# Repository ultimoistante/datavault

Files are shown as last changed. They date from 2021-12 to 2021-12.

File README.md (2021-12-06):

# DataVault - a simple, cheap, and effective backup unit for cloud storage services

## preface
The reason I've built this device is rather simple: I have a private NextCloud instance running on a my small server where I (and my family) store some important data. Since it is not wise to keep "all eggs in one bucket", and since that "two copies are better than one", I made this device to automatically keep a synchronized copy of all my data (from my NextCloud server and from some GDrive accounts) to its SSD drive.

## the device
The device is rather simple: just an old Raspberry Pi model B+, a SATA SSD drive, an USB/SATA adapter, and an ESP8266 MCU board (NodeMCU).
Everything fits perfectly in the case of an old ADSL modem (Alice Gate Plus, by Pirelli/Telecom Italia).

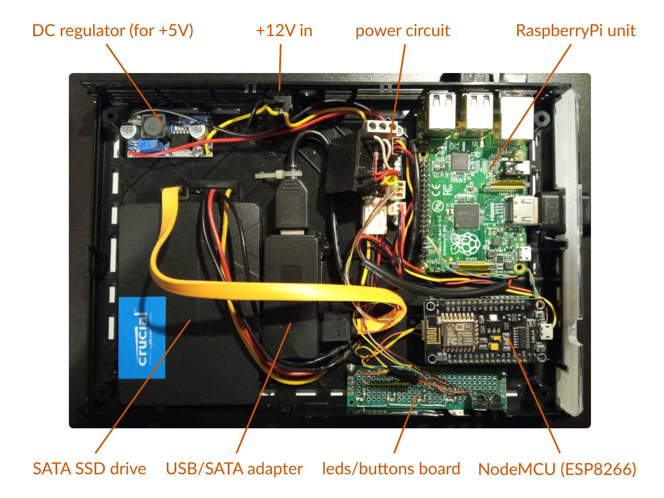
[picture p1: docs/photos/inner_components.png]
inner components

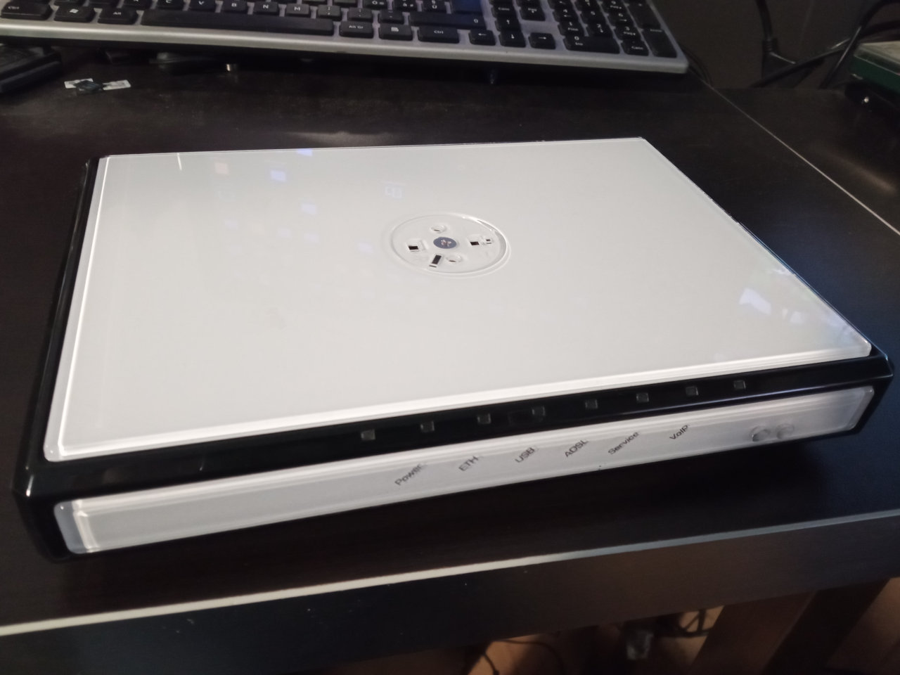
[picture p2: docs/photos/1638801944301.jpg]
outer 1

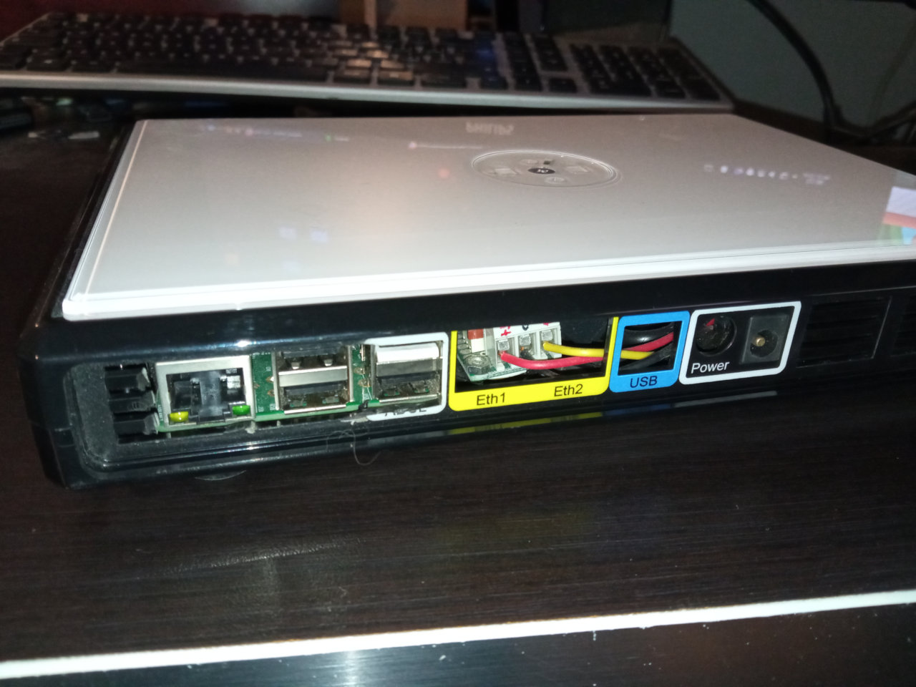
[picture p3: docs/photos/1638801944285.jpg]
outer 2

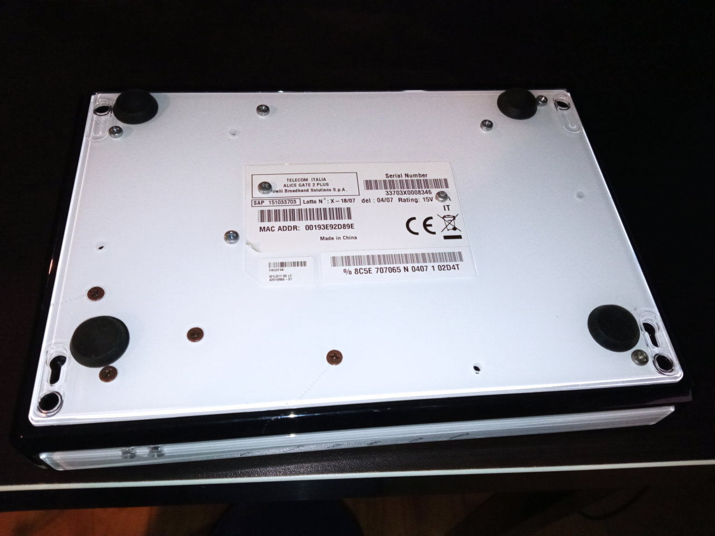
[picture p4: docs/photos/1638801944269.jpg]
outer 3


## working principle
Everything is powered by an external 12V DC adapter. In the box there is a DC stepdown regulator for +5V line. These two voltage levels are connected on the "power circuit" board.

The ESP8266 unit is always powered (consuming almost nothing), it's connected to home network via wifi, and it acts as a "timer" for the Raspberry Pi unit. Once a day (in my case during the night), it switches a relay giving power to the Raspberry Pi, that is connected to the network via ethernet cable. Once the RaspberryPi system it's booted, it starts a simple python application that sequentially runs some tasks defined in a json configuration file. Each task spawns an **RClone** (https://rclone.org/) subprocess that connects to the remote cloud repository and *syncs* (in one way mode) all remote files to local SATA SSD drive.

## the ESP8266 unit
Firmware and webservice sources are under **sources/esp8266** folder. The code was written using **PlatformIO** (https://platformio.org/) on VSCode.
Unlike *almost* every ESP8266 firmwares you can find on the network, to connect this device to the WiFi network you don't need to write your network credentials in the sources, since I've added an handy **WPS** feature. You just need to enable WPS on your router, and push the WPS button on the ESP8266 unit (connected to pin D6). Once successfully paired, the device will connect to NTP server, taking current date/time. I've also added a **mDNS** feature, so you can reach its settings page opening the address **http://dvctrl.local/** with a modern browser from your local network.

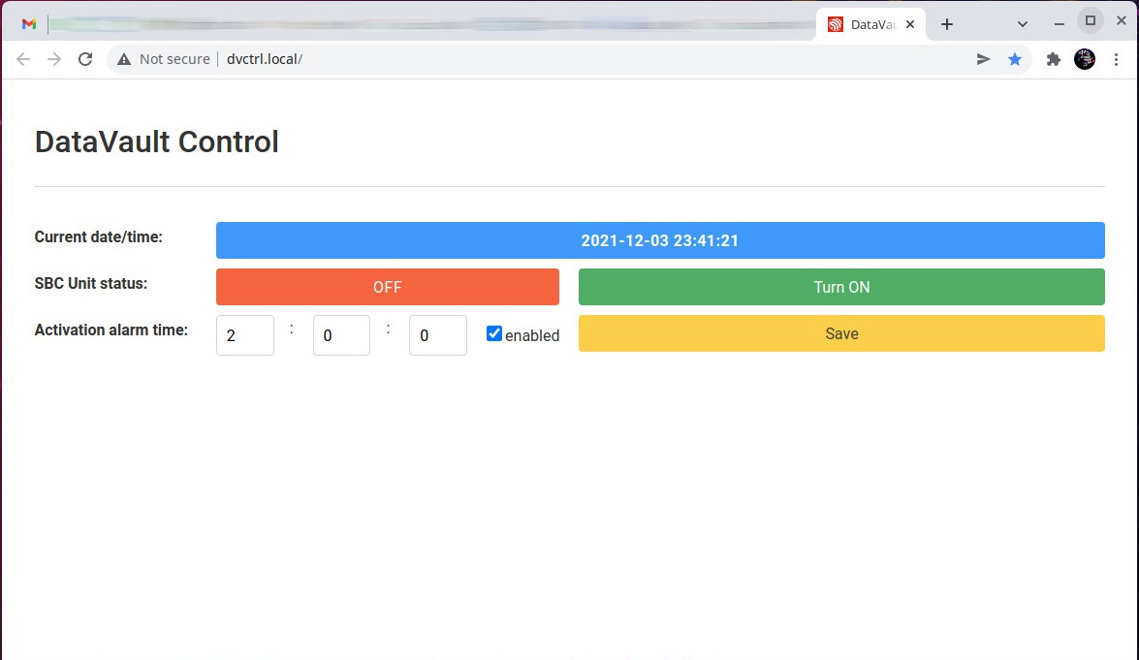
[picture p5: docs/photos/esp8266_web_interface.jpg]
esp8266 web interface


From the web interface you can see date/time from the device, the power status of the SBC unit (the RaspberryPi), you can turn it on or off, and set/enable/disable the daily activation time.

This simple webpage is built with:
 - **Vue.js** v2 (https://vuejs.org/)
 - **Chota** micro CSS framework (https://github.com/jenil/chota)
 - **notyf** for toast notifications (https://carlosroso.com/notyf/)
 - **reconnectingWs** for websocket communication

## the RaspberryPi unit
Since I'm using an old B+ model, I've installed **DietPi** (https://dietpi.com/)

I've formatted the SATA SSD drive with only one ext4 partition, and mounted under **/mnt/storage**, adding a line in **/etc/fstab**:
    
    UUID=[your UUID here] /mnt/storage ext4 noatime,lazytime,rw,nofail,noauto,x-systemd.automount

You can find the sources for python application **(syncworker)** under sources/raspberrypi/syncworker (in this repository). You need to correctly configure **config.json** file with your tasks (there is a file named config-example.json, to be renamed to config.json).

To create RClone remotes, refer to RClone documentation (https://rclone.org/remote_setup/). In the README file under syncworker folder there is an example to configure GDrive remotes (basically you need to connect to the RaspberryPi system via SSH, and issue some shell commands).

On the DietPi system, I've placed syncworker application folder under /mnt/storage/datavault (the root of SSD partition).

### autostart application at boot (on DietPi)
Since DietPi doesn't have a rc.local file (it uses systemd), you need to put a bash script under **/var/lib/dietpi/postboot.d/**

    nano /var/lib/dietpi/postboot.d/datavault.sh

with this content:

    #!/bin/bash

    systemctl restart systemd-timesyncd

    sleep 2

    cd /mnt/storage/datavault/syncworker
    ./run.sh

then set permissions:

    chmod 755 /var/lib/dietpi/postboot.d/datavault.sh

## electrical connections
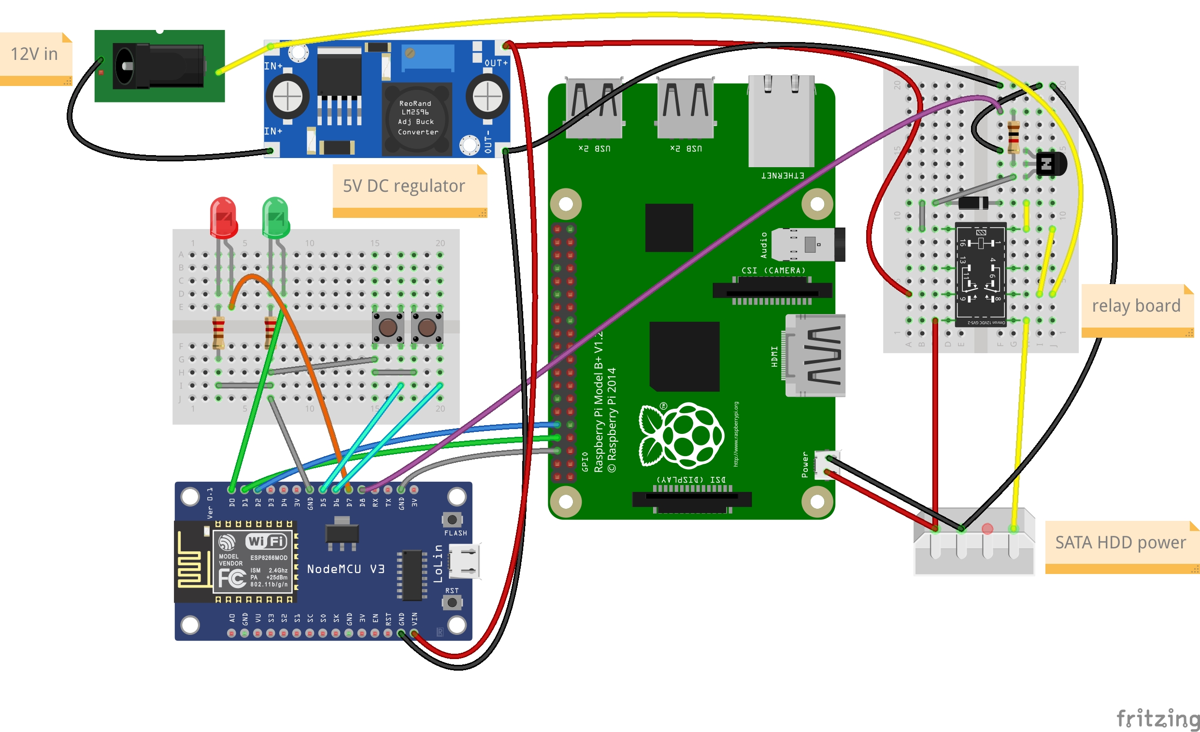
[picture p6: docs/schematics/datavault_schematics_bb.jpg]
electrical connections


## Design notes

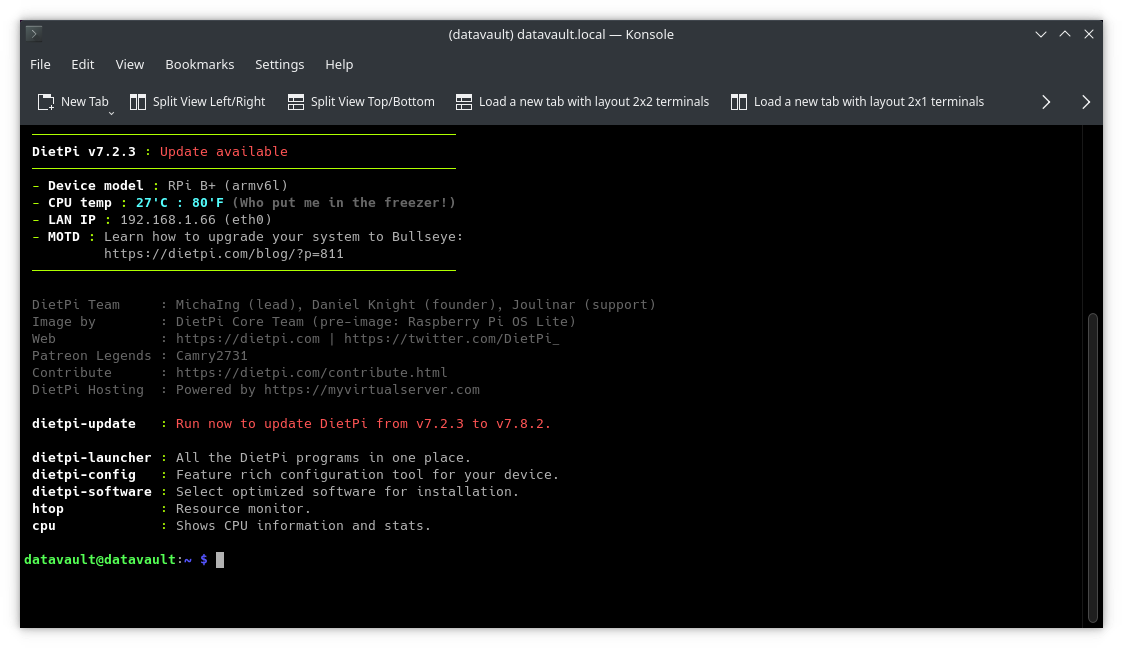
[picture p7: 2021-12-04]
docs/photos/datavault_ssh.png

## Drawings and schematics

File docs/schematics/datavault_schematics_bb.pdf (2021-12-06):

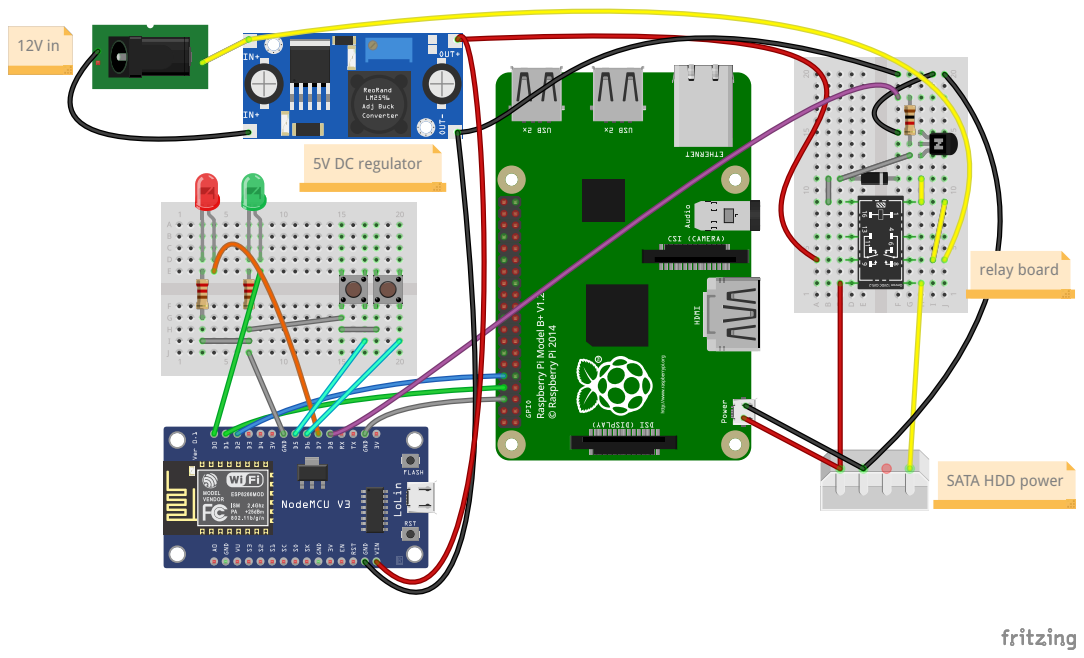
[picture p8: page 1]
5V DC regulator; relay board

SATA HDD power

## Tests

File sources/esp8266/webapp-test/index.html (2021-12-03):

# DataVault Control

Current date/time:

{{currentDateTime}}

SBC Unit status:

{{sbcPowerStatusString}}

{{sbcPowerButtonText}}

Activation alarm time:

:

: enabled

Save

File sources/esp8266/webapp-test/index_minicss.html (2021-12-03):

DataVault Control

Current date/time:

{{currentDateTime}}

SBC Unit status:

{{sbcPowerStatusString}}

##### Autoactivation time:

: :

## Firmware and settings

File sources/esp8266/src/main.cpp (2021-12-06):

/*
 * DataVault esp8266-power-manager firmware
 *
 * Written by Salvatore Carotenuto (ultimoistante)
 *
 * Changelog:
 *    2021-06-12:
 *       .handled SBC power on/off from web app;
 *       .handled timer;
 *       .added notyf (css toast notifications);
 *       .added activationTime saving from webapp;
 *       .rewritten webapp with chota css;
 *       .fixed websocket status request;
 *    2021-06-06:
 *       .added ESP8266TimeAlarms library
 *       .added EEPROM handling
 *       .added timeAlarm handling
 *    2021-06-05:
 *       .fixed exception on webservice start
 *       .forked esp8266 project code from old datavault repo
 *    2021-05-17:
 *       .rebooted project under PlatformIO
 *       .started adding Vue/websocket based web app
 *       .mDNS service now works
 *       .readded NTP client code
 *    2021-01-26:
 *       .added handling of raspberryPi status led to StatusLedHandler
 *       .started adding logging and receive methods to SerialHandler
 *    2020-12-30:
 *       .rewritten WiFi connection code in event-driven mode
 *       .replaced NTP client code, adding from: https://github.com/gmag11/ESPNtpClient
 *    2020-12-27:
 *       .changed pin assignments
 *       .added status led patterns
 *       .added wifi connection
 *       .added basic webserver
 *       .started adding mDNS support
 *    2020-12-16:
 *       .added jLed library
 *       .started writing
*/

// ----------------------------------------------------------------------------
// Hardware connections:
//
//    +-------------------+
//    |A0          D0 [16]| - rPi power status LED
//    |            D1 [05]| - SoftwareSerial RX (to RaspberryPi serial TX)
//    |            D2 [04]| - SoftwareSerial TX (to RaspberryPi serial RX)
//    |            D3 [00]| - __RESERVED__
//    |            D4 [02]| - (LED_BUILTIN)
//    |                3v3| -
//    |                GND| -
//    |            D5 [14]| - Power button (for rPi)
//    |            D6 [12]| - WPS request button
//    |            D7 [13]| - Power Manager (this device) status LED
//    |            D8 [15]| - Power relay control
//    |       D9 / RX [03]| - 
//    |      D10 / TX [01]| - to RaspberryPi serial RX
//    |                GND| -
//    |                3v3| -
//    +-------------------+
//
// ----------------------------------------------------------------------------

#include <ESP8266WiFi.h>
#include <ESPAsyncWebServer.h>
#include <ESP8266mDNS.h> // Include the mDNS library
#include <FS.h>
#include <jled.h>
#include <AceButton.h>
using namespace ace_button;
#include <ESPNtpClient.h>           // https://github.com/gmag11/ESPNtpClient
#include <EEPROM.h>
#include <ESP8266TimeAlarms.h>      // https://github.com/jhagberg/ESP8266TimeAlarms
#include <SoftwareSerial.h>
//
#include "defines.h"
#include "SerialHandler.h"
#include "WiFiHandler.h"
#include "WebService.hpp"
#include "StatusLedHandler.h"
#include "StaticData.hpp"

// ----------------------------------------------------------------------------

// user buttons
AceButton powerButton(POWER_BUTTON_PIN);
AceButton wpsButton(WPS_BUTTON_PIN);

// status leds
auto deviceStatusLed = JLed(DEVICE_STATUS_LED_PIN);
auto rpiStatusLed = JLed(RPI_STATUS_LED_PIN);

bool rpiPowered = false;
uint8_t rpiPoweredBy = SBC_POWERED_BY_NONE;

// ----------------------------------------------------------------------------

// SoftwareSerial swSerial;
SoftwareSerial swSerial;
SerialHandler serialHandler;

// handler for wifi connection
WiFiHandler wifiHandler;

StatusLedHandler statusLedHandler;

NTPEvent_t ntpEvent;            // Last triggered event
bool ntpEventTriggered = false; // True if a time even has been triggered
bool ntpSynchronized = false;

char serialResponseBuffer[64];

// ----------------------------------------------------------------------------

#define MDNS_UPDATE_TIME_INTERVAL 2000
bool mDNSStarted = false;
unsigned long nextMDNSUpdateTime = 0;

unsigned long webServerActivationTime = 0;

unsigned long timeAlarmInstanceTime = 0;
unsigned long nextAlarmsServiceTime = 0;

unsigned long powerOffTime = 0;

// ----------------------------------------------------------------------------

// millisecond timer object
os_timer_t msecTimer;
uint8_t timerTickCounter = 0;

// ----------------------------------------------------------------------------

AlarmId activationTimerAlarmId = 0;

// ----------------------------------------------------------------------------


void msecTimerCallback(void* pArg)
    {
    statusLedHandler.update();
    //
    powerButton.check();
    wpsButton.check();
    }


// -----------------------------------------------------------------------------


void setMosfetStatus(bool status)
    {
    digitalWrite(MOSFET_CONTROL_PIN, status ? HIGH : LOW);
    }


// ----------------------------------------------------------------------------


void onConnectCallback()
    {
    // Serial.println(">>> onConnectCallback");
    //
    // starts the mDNS responder for <devicename>.local
    if (!MDNS.begin(DEVICE_MDNS_HOSTNAME))
        {
        Serial.println("[E] Error setting up MDNS responder!");
        }
    else
        {
        MDNS.addService("http", "tcp", 80);
        Serial.println("[I] MDNS responder started");
        mDNSStarted = true;
        }
    //
    // defers webserver activation time, at 1 second from now
    webServerActivationTime = millis() + 1000;
    //
    // starts NTP service
    NTP.setTimeZone(TZ_Europe_Rome);
    NTP.onNTPSyncEvent([](NTPEvent_t event)
        {
        ntpEvent = event;
        ntpEventTriggered = true;
        });
    NTP.begin();
    }


// -----------------------------------------------------------------------------


void processNtpEvent(NTPEvent_t ntpEvent)
    {
    switch (ntpEvent.event)
        {
            case timeSyncd:
            case partlySync:
            case syncNotNeeded:
            case accuracyError:
                Serial.printf("[I] [NTP-event] %s\n", NTP.ntpEvent2str(ntpEvent));
                ntpSynchronized = true;
                //
                // defers timeAlarm instance to 0.5 second from now
                timeAlarmInstanceTime = millis() + 500;
                //
                break;
            default:
                break;
        }
    }


// -----------------------------------------------------------------------------


void handleButtonEvent(AceButton* button, uint8_t eventType, uint8_t /*buttonState*/)
    {
    uint8_t pin = button->getPin();
    //
    if (pin == POWER_BUTTON_PIN)
        {
        switch (eventType)
            {
            // Interpret a Released event as a Pressed event, to distiguish it
            // from a LongPressed event.
                case AceButton::kEventReleased:
                    if (!rpiPowered)
                        {
                        setMosfetStatus(true);
                        rpiPowered = true;
                        rpiPoweredBy = SBC_POWERED_BY_USER;
                        statusLedHandler.setRaspberryPiStatus(StatusLedHandler::RPI_STATUS_BOOTING);
                        }
                    break;

                    // LongPressed event
                case AceButton::kEventLongPressed:
                    if (rpiPowered)
                        {
                        setMosfetStatus(false);
                        rpiPowered = false;
                        rpiPoweredBy = SBC_POWERED_BY_NONE;
                        rpiStatusLed.FadeOff(500).Repeat(1);
                        }
                    break;
            }
        }
    //
    else if (pin == WPS_BUTTON_PIN && eventType == AceButton::kEventReleased)
        {
        if (wifiHandler.getCurrentStatus() == WiFiHandler::STATUS_STAMODE_NOT_CONNECTED)
            {
            wifiHandler.tryWPSConnection();
            }
        }
    }


// -----------------------------------------------------------------------------


void serialReceiveMessageHandler(char** tokens, int tokenCount)
    {
    //
    if (tokenCount)
        {
        //
        // powerBy? request
        if (strcmp(tokens[0], "powerBy?") == 0)
            {
            sprintf(serialResponseBuffer, "powerBy=%s", (rpiPoweredBy == SBC_POWERED_BY_TIMER) ? "timer" : ((rpiPoweredBy == SBC_POWERED_BY_USER) ? "user" : "none"));
            serialHandler.sendMessage(serialResponseBuffer);
            }
        //
        // bootComplete! event
        else if (strcmp(tokens[0], "bootComplete!") == 0)
            {
            statusLedHandler.setRaspberryPiStatus(StatusLedHandler::RPI_STATUS_BOOTED);
            }
        //
        // powerOff request
        if (tokenCount >= 2 && strcmp(tokens[0], "powerOff") == 0)
            {
            unsigned int delay = atoi(tokens[1]);
            if (delay > 0)
                {
                Serial.printf("[I] powerOff request received. Shutting down RaspberryPi in %d seconds\n", delay);
                statusLedHandler.setRaspberryPiStatus(StatusLedHandler::RPI_STATUS_SHUTTING_DOWN);
                powerOffTime = millis() + (delay * 1000);
                }
            }
        }
    }


// -----------------------------------------------------------------------------


void eepromWriteSignature()
    {
    // writes default signature: "DVCTRL10" (DataVault Controller 1.0)
    EEPROM.write(0, 'D');
    EEPROM.write(1, 'V');
    EEPROM.write(2, 'C');
    EEPROM.write(3, 'T');
    EEPROM.write(4, 'R');
    EEPROM.write(5, 'L');
    EEPROM.write(6, '1');
    EEPROM.write(7, '0');
    EEPROM.commit(); // stores data to EEPROM
    }


// -----------------------------------------------------------------------------


void eepromWriteActivationTime()
    {
    EEPROM.put(EEPROM_DATA_START_ADDR, activationTime);
    EEPROM.commit(); // stores data to EEPROM
    }


// -----------------------------------------------------------------------------


void eepromInit()
    {
    uint16_t start_addr;
    // expected signature: "DVCTRL10" (DataVault Controller 1.0)
    char signature[8];
    for (byte i = 0; i < 8; i++)
        signature[i] = EEPROM.read(i);
    if (memcmp(signature, "DVCTRL10", 8) == 0)
        {
        // good signature, reads structures from eeprom
        start_addr = 8; // data start address is after signature
        EEPROM.get(start_addr, activationTime);
        Serial.println("[I] found valid eeprom signature");
        }
    else
        {
        // uninitialized eeprom, or bad signature
        Serial.print("[W] no valid eeprom signature found. Initializing... ");
        // stores default values
        activationTime.hour = 0;
        activationTime.minute = 0;
        activationTime.second = 0;
        activationTime.enabled = 0;
        //
        eepromWriteSignature();
        eepromWriteActivationTime();
        Serial.println("done.");
        }
    }


// -----------------------------------------------------------------------------


void onActivationTimerAlarm()
    {
    Serial.printf("[I] timerAlarm triggered at %s\n", NTP.getTimeDateString(time(NULL), "%04Y-%02m-%02d %02H:%02M:%02S"));
    //
    websocket.textAll("{\"event\":\"timerTriggered\"}");
    //
    if (!rpiPowered)
        {
        Serial.println("[I] activated SBC power");
        setMosfetStatus(true);
        // sets rpiPoweredBy variable as "powered by timer"
        rpiPoweredBy = SBC_POWERED_BY_TIMER;
        statusLedHandler.setRaspberryPiStatus(StatusLedHandler::RPI_STATUS_BOOTING);
        rpiPowered = true;
        }
    else
        Serial.println("[I] SBC power already active, skipping");
    }


// -----------------------------------------------------------------------------


void setup()
    {
    //
    // sets button pins as input, with pullup
    pinMode(POWER_BUTTON_PIN, INPUT_PULLUP);
    pinMode(WPS_BUTTON_PIN, INPUT_PULLUP);
    // sets mosfet control pin mode
    pinMode(MOSFET_CONTROL_PIN, OUTPUT);
    //
    setMosfetStatus(false);
    //
    Serial.begin(HW_SERIAL_BAUDRATE);
    //
    swSerial.begin(SW_SERIAL_BAUDRATE, SWSERIAL_8N1, SW_SERIAL_RX_PIN, SW_SERIAL_TX_PIN);
    serialHandler.begin(&swSerial);
    serialHandler.setPacketDelimiterChars('{', '}');
    serialHandler.setTokenCharSeparators("|,");
    serialHandler.setMessageHandler(serialReceiveMessageHandler);
    //
    SPIFFS.begin();
    //
    EEPROM.begin(512);
    delay(500);
    eepromInit();
    //
    // starts millisecond timer
    os_timer_setfn(&msecTimer, msecTimerCallback, NULL);
    os_timer_arm(&msecTimer, 1, true);
    //
    // Configure the ButtonConfig with the event handler.
    ButtonConfig* buttonConfig = ButtonConfig::getSystemButtonConfig();
    buttonConfig->setEventHandler(handleButtonEvent);
    buttonConfig->setFeature(ButtonConfig::kFeatureLongPress);
    buttonConfig->setFeature(ButtonConfig::kFeatureRepeatPress);
    buttonConfig->setFeature(ButtonConfig::kFeatureSuppressAfterLongPress);
    //
    statusLedHandler.begin(&deviceStatusLed, &rpiStatusLed);
    //
    delay(500);
    wifiHandler.setOnConnectCallback(onConnectCallback);
    wifiHandler.begin(&statusLedHandler);
    delay(1000);
    }


// ----------------------------------------------------------------------------


void loop()
    {
    unsigned long now = millis();
    //
    serialHandler.doReceive();
    //
    // checks if it's time to start webserver
    if (webServerActivationTime && now >= webServerActivationTime)
        {
        webServerActivationTime = 0;
        initWebService(&server, &websocket);
        }
    //
    // checks if it's time to instance defined alarmTime
    if (timeAlarmInstanceTime && now >= timeAlarmInstanceTime)
        {
        timeAlarmInstanceTime = 0;
        //
        // disable/free previously created timer, if any
        if (activationTimerAlarmId)
            {
            Alarm.disable(activationTimerAlarmId);
            Alarm.free(activationTimerAlarmId);
            }
        //
        if (activationTime.enabled)
            {
            Serial.printf("[I] setting timerAlarm at %02d:%02d:%02d\n", activationTime.hour, activationTime.minute, activationTime.second);
            activationTimerAlarmId = Alarm.alarmRepeat(activationTime.hour, activationTime.minute, activationTime.second, onActivationTimerAlarm);
            }
        else
            {
            Serial.println("[W] timerAlarm disabled");
            }
        }
    //
    // checks if raspberryPi has requested power off and it's time to switch down power relay
    if (powerOffTime != 0 && now >= powerOffTime)
        {
        powerOffTime = 0;
        setMosfetStatus(false);
        rpiPowered = false;
        rpiPoweredBy = SBC_POWERED_BY_NONE;
        rpiStatusLed.FadeOff(500).Repeat(1);
        }
    //
    // updates Alarms service
    if (activationTimerAlarmId && now >= nextAlarmsServiceTime)
        {
        nextAlarmsServiceTime = now + 500;
        Alarm.delay(5);
        }
    //
    // updates mDNS service
    if (mDNSStarted && now >= nextMDNSUpdateTime)
        {
        nextMDNSUpdateTime = now + MDNS_UPDATE_TIME_INTERVAL;
        MDNS.update();
        //
        }

    // checks for NTP events
    if (ntpEventTriggered)
        {
        ntpEventTriggered = false;
        processNtpEvent(ntpEvent);
        }

    // checks if got a request to save activationTime
    if (gotSaveAlarmTimeRequest)
        {
        gotSaveAlarmTimeRequest = false;
        websocketBusyWait = true;
        // saves activation time structure to eeprom
        Serial.printf("[I] Saving activation time: %02d:%02d:%02d, enabled: %d\n", activationTime.hour, activationTime.minute, activationTime.second, activationTime.enabled);
        eepromWriteActivationTime();
        //
        // requests reinstancing of timer
        timeAlarmInstanceTime = now + 100;
        //
        websocketBusyWait = false;
        websocket.textAll("{\"event\":\"savedActivationTime\"}");
        }

    // checks if got a request to set SBC power on/off (from web interface)
    if (gotSetPowerRequest)
        {
        gotSetPowerRequest = false;
        //
        setMosfetStatus(gotSetPowerRequestStatus);
        rpiPoweredBy = gotSetPowerRequestStatus ? SBC_POWERED_BY_USER : SBC_POWERED_BY_NONE;
        if (gotSetPowerRequestStatus)
            statusLedHandler.setRaspberryPiStatus(StatusLedHandler::RPI_STATUS_BOOTING);
        else
            rpiStatusLed.FadeOff(500).Repeat(1);
        //
        String eventPayload = "{\"event\":\"setPower\", \"status\":";
        eventPayload += gotSetPowerRequestStatus ? "true }" : "false }";
        websocket.textAll(eventPayload.c_str());
        }
    //
    }

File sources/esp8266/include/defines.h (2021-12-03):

#ifndef DEFINES_H
#define DEFINES_H

// ----------------------------------------------------------------------------

#define DEVICE_STATUS_LED_PIN   13  // D7
#define RPI_STATUS_LED_PIN      16  // D0

#define WPS_BUTTON_PIN          14  // D5
#define POWER_BUTTON_PIN        12  // D6  

// #define MOSFET_CONTROL_PIN       2  // D4
#define MOSFET_CONTROL_PIN      15  // D8

#define SW_SERIAL_RX_PIN         5  // D1
#define SW_SERIAL_TX_PIN         4  // D2

// ----------------------------------------------------------------------------

#define HW_SERIAL_BAUDRATE         115200
#define SW_SERIAL_BAUDRATE         9600

// ----------------------------------------------------------------------------

#define EEPROM_DATA_START_ADDR	8

// ----------------------------------------------------------------------------

// #define DEVICE_STATUS_LED_MODE_NOT_CONNECTED 0
// #define DEVICE_STATUS_LED_MODE_TRYING_WPS    1
// #define DEVICE_STATUS_LED_MODE_CONNECTING    2
// #define DEVICE_STATUS_LED_MODE_CONNECTED     3

#define DEVICE_MDNS_HOSTNAME    "dvctrl"

// ----------------------------------------------------------------------------

#define NTP_SERVER_POOL         "europe.pool.ntp.org"
// #define NTP_TIMEOUT         1500
// #define NTP_PRINT_TIME_INTERVAL   1000
// #define NTP_SERVER_POOL         "europe.pool.ntp.org"
#define NTP_UTC_OFFSET_SECS        3600
// #define NTP_UPDATE_INTERVAL     60000

// ----------------------------------------------------------------------------

#define WEBSERVICE_PORT             80
#define WEBSERVICE_TIMEOUT_MSEC     2000

#define WEBSOCKET_SERVER_PORT       81

// ----------------------------------------------------------------------------

#define SBC_POWERED_BY_NONE         0
#define SBC_POWERED_BY_TIMER        1
#define SBC_POWERED_BY_USER         2

// ----------------------------------------------------------------------------

#endif

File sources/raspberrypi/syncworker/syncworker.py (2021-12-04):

import os
import sys
import io
import json
import getopt
import logging
import subprocess
import serial
import logging
import time
from datetime import datetime
from schema import Schema, And, Use, Optional, SchemaError
from logging.handlers import RotatingFileHandler
from logutils import ColoredFormatter
from serial_handler import SerialHandler

# ------------------------------------------------------------------------------

__VERSION__ = "1.0.0"

CONFIG_FILE = "config.json"

RCLONE_COMMAND = "rclone"

CHECK_NTP_POLLING_SECS = 10

DEFAULT_SHUTDOWN_GRACE_TIME_SECS = 5
DEFAULT_POWEROFF_GRACE_TIME_SECS = 60

# ------------------------------------------------------------------------------

# --- getopt settings

short_options = "hf:v"
long_options = ["help", "force-power-by="]

# ------------------------------------------------------------------------------

# --- config schemas

system_config_schema = Schema(
    {
        Optional("shutdown_grace_time_secs"): And(Use(int)),
        Optional("poweroff_grace_time_secs"): And(Use(int))
    }
)

serial_config_schema = Schema(
    {
        "port": str,
        "baudrate": int,
        "bytesize": str,
        "parity": str,
        "stopbits": str,
    }
)

log_config_schema = Schema(
    {
        "path": str,
        "tasks_subdir_format": str,
        "filename": str,
        "max_bytes": int,
        "files_count": int,
    }
)


tasks_config_schema = Schema(
    {Optional("run_as_user"): And(Use(str)), "local_root_path": str}
)


task_schema = Schema(
    {
        "command": str,
        Optional("flags"): And(Use(str)),
        "remote": {
            "id": str,
            "path": str,
        },
        Optional("local_path"): And(Use(str)),
        Optional("logfile"): And(Use(str)),
        "enabled": bool,
    }
)

# ------------------------------------------------------------------------------

poweredBy = None
forcePoweredBy = None

# ------------------------------------------------------------------------------


def init_logging(config):
    # creates log dir, if it doesn't exists
    if not os.path.exists(config["path"]):
        os.makedirs(config["path"])

    # creates logger
    log = logging.getLogger()

    # adds console handler
    ch = logging.StreamHandler()
    ch.setLevel(logging.DEBUG)
    cf = ColoredFormatter("%(asctime)s [%(levelname)-10s] %(msg)s")
    ch.setFormatter(cf)
    log.addHandler(ch)

    # adds file handler
    fh = RotatingFileHandler(
        os.path.join(config["path"], config["filename"]),
        maxBytes=config["max_bytes"],
        backupCount=config["files_count"],
    )
    fh.setLevel(logging.DEBUG)
    fh.setFormatter(logging.Formatter("%(asctime)s\t[%(levelname)-10s]\t%(msg)s"))
    log.addHandler(fh)

    # Set log level
    log.setLevel(logging.DEBUG)

    return log


# ------------------------------------------------------------------------------


def check_ntp():
    synchronized = False
    #
    args = ["timedatectl", "status"]
    proc = subprocess.run(args, stdout=subprocess.PIPE, stderr=subprocess.STDOUT, universal_newlines=True)
    output_lines = proc.stdout.split("\n")
    for line in output_lines:
        if not synchronized and "synchronized: yes" in line.rstrip():
            synchronized = True
    #
    return synchronized


# ------------------------------------------------------------------------------


def request_shutdown(serialHandler, shutdown_delay, poweroff_delay):
    log.info("requesting shutdown in {shutdown_delay} seconds, and power off in {poweroff_delay} seconds".format(shutdown_delay=shutdown_delay, poweroff_delay=poweroff_delay))
    serialHandler.write_message("powerOff|{}".format(poweroff_delay), None)
    os.system('(sleep {} && shutdown -h) &'.format(shutdown_delay))


# ------------------------------------------------------------------------------
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

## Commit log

2021-12-04 added raspberrypi sources
2021-12-06 code cleaning; documentation fix
    [datavault_schematics.fzz]
